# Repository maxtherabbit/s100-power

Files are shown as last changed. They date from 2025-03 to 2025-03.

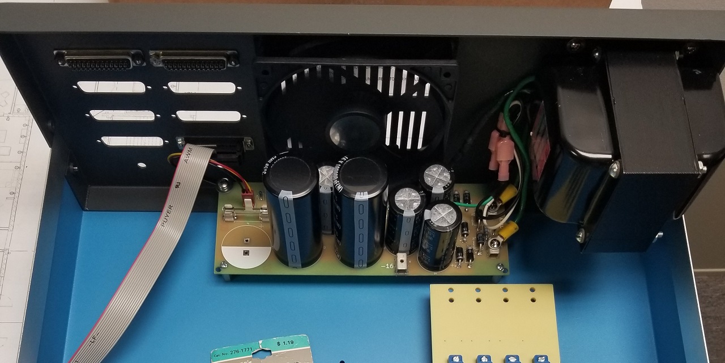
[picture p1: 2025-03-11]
20250304_174920_cover.jpg

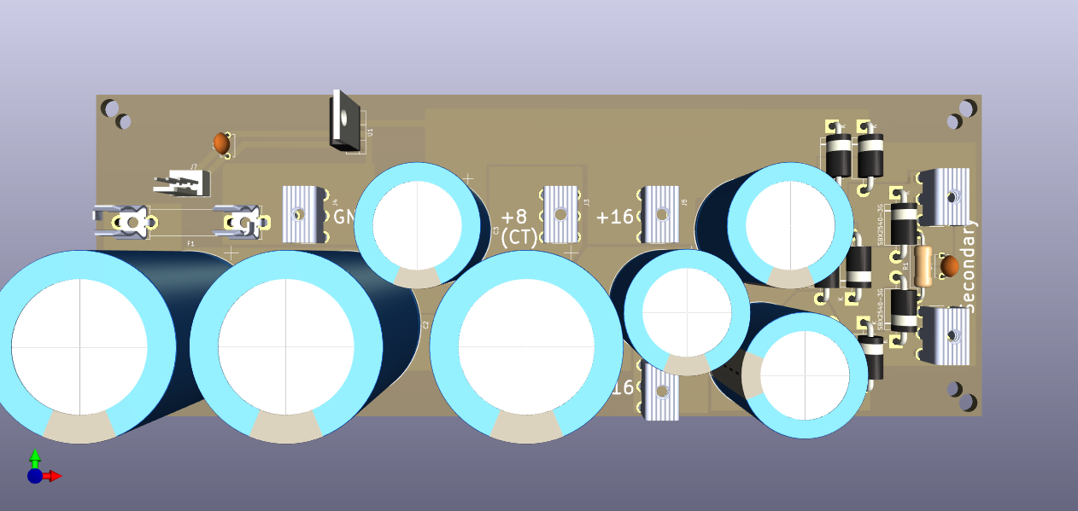
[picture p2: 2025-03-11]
s100 power.png

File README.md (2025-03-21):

# s100-power
PCB for S100 Power Supply which fits both original Altair and Clone cabinets

Based on circuit designed by Gifford Toole. Provides 10A (with Hammond 167S12) or 20A (with Hammond 167V12) total current. Mounting provisions for both original Altair cabinet as well as clone cabniet designed by Mike Douglas.
My clone cabinet was purchased from https://adwaterandstir.com/ in 2024 and uses M4 hardware. The original one sold by Mike might use 6-32 instead. Make sure you check this before ordering the standoffs!
For the one using M4, I included appropriate length standoffs in the BOM. The M4 ones attach to the screws which connect the rear panel to the bottom panel. Get longer M4 screws and thread them into the existing welded screw bosses from the bottom, then attach standoffs to them. Affix the longer 4-40 standoffs to the front of the PCB with 4-40 screws, then bolt PCB to M4 standoffs with the original M4 screws which came with the cabniet.

I found that the Hammond 167S12 transformer fit the two pre-drilled holes in the rear panel, on the right side. You will need to drill two additional holes above the pre-drilled ones at the same width apart to secure the transformer properly.

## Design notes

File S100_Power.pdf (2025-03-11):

## GEFH H(, o E

s

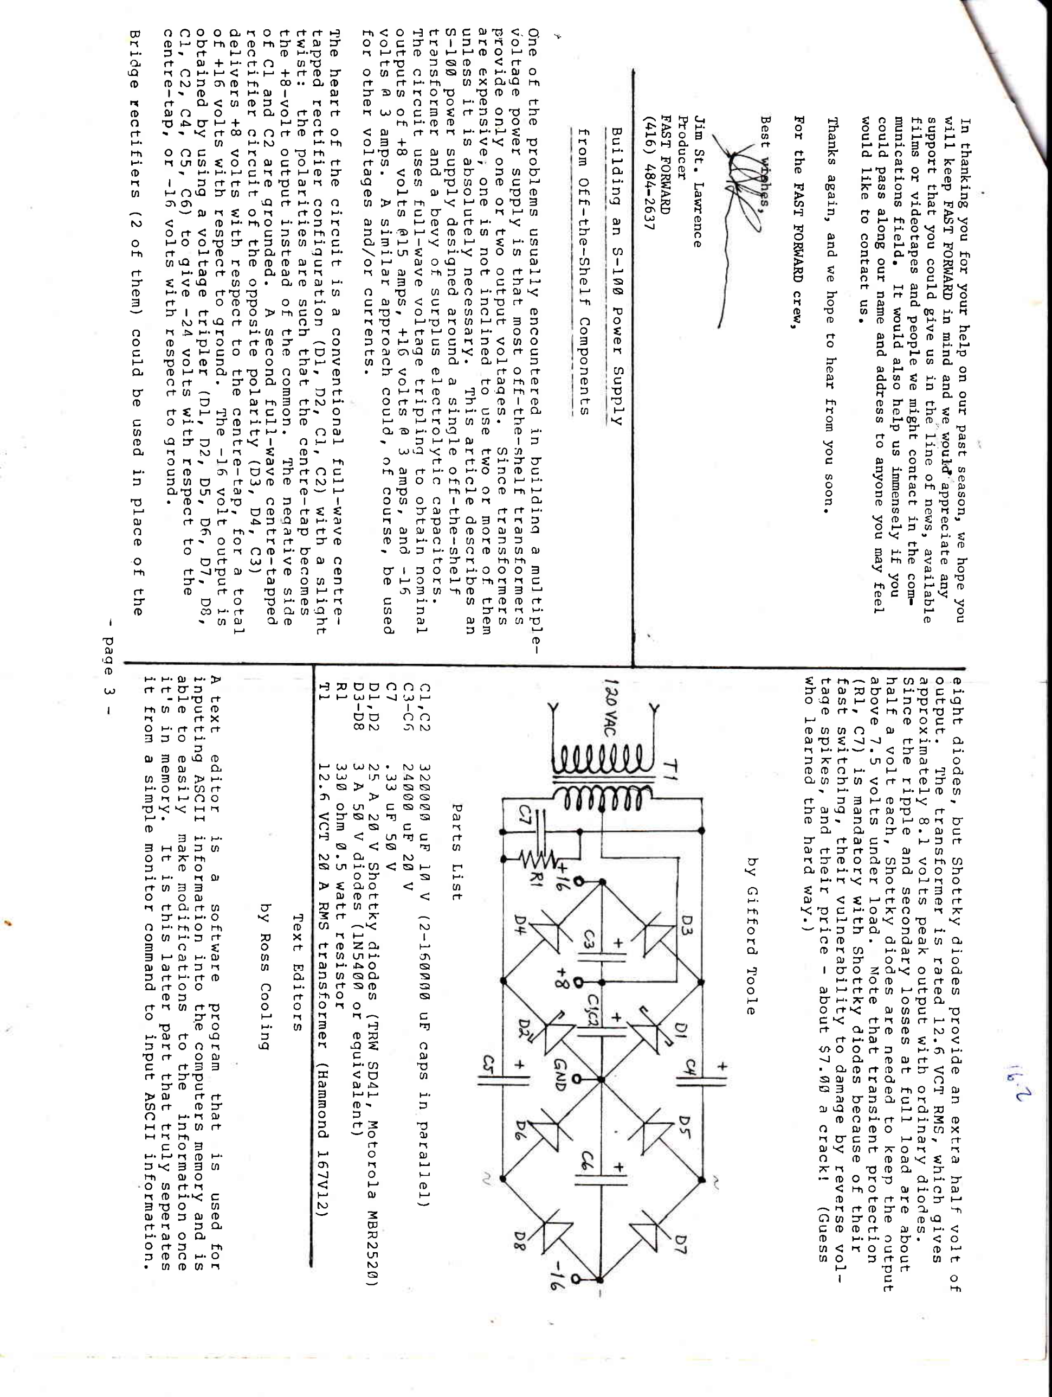
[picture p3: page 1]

rd | H | d O E Fho { H
o | y | o o c P.C P.5 FI | $ | tr d 5 HE H
5 | HHH.3'o | Hd d | 7f | oQ.o | o o | :t J | o | !) | FtFo) oHEdodoS D | H.F] H.E | O F rn | 0q | ,f o O | m'O P.
(a | F. | o H. o rt@ H | 3 | doJ | o.db ! | O HrrO | tE< rri | O H.og | Fro O | O | OSodO | -t
F | !] | octq H0, c rd
{ | o- | 5 | O'O | O Hl
F | { | !) 6 | 0 0
t | o | oE | dF=tsi
fr | H0rHiu\<
o | !t | 5d5o,tJo FlOtrAro.t
O | 'o | o41 | 0sp.rt € | o | . o OE P.5 . | tro< | !t fr | p) Ho O E O
o | 5 o.'d | H.H o. Htr 5'd 5 | oJooo. o | grH | o pr | a-o d H.$ 5 Ft | a.o o 5 5
|l | 0.o h | o ItE d | tr Fl | O O H,it{ Fl
o | o HoQ O O
!H+!
- n -i-€p
o | ho5trd C | D | OOrt' 5 ts. J | 6.a o | yEdo | :o
o | o B 0, hp p) O | 5oO | 'do 5 | (D5fr5EO . | a | oB5 \< o F.{ o. o H5 0 () C< | . r.{ f | aro E ts.:'AJ fr O hto < o:]. goro

< o p.0rrd rto O HE O
o 6 E pjY oacrY

FHO at

tE
o
a
d

o'H o. cu) tsio d
SO @iI, o.
tst s'= | tr{ r>0, NiD | €
o\t | H
(!o!5
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
'ld.5
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
af :t
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
@ o oo o o,Fr o rtrtrt€ | rr|< o €rt(/lc orc, <.o Fr O }.(rFhO O rn:fd 0, !t O O tr 5x I 5 Fr Fr O J
ts. ,..r | FO | OP.TOO | FlPr?OOPHOOf-O
O, ri | o +P.rf.) | oE | r?! | f aO | < rt lQ (.)H.P<H. | l-+rtO!t | OOtrOOEoOts'o,O
O | ON:,5\OFtr | o..OJO | rt | rtF'Hr | OXO,tO;6
l- O iH.O | I | O :tDOrrOrO | rCOO
E | .r | O,<OO5< | nl-l | O | OnOts.O | rr
o | o.) | o | no,ortorf | Fr(r)ogStrrJOld5
O E,sEP+ | P:tO | iarH'OO | (/)JOo
rt | r-<.r@Or).f | OffO | <O | r+FlriP'P'P€ P. | O P.N | P.Hr O3+ | O<<Ord Fh ootr | <x | o'uFh | HECDtr0ro | o | nFl P. nUnO{OOOtrOP.rt | rtO | (/)lCOt-.O | O
o | t H.H.PCrrriHoit | 0r. <oo,'dcr | 5o<,
n | I | f dfrP.Ot,or11O | !O O(n lOmOOtrP
a | P .)o 5t, - | tr n | o | P | o, Po 5 r5 o
JrOr | \QdH'oo | o>r+Hl | <PooE=
-Orr€OFl | rtop. | OgU | tr | nPU)
orr<of+ | trf oho | 5P..a)P<oOo.t | G
O | POOiO:trtrOOH.tr | O,=lPl<OP | {H'(, Hi rt | HO | 50,rf | -2P' | \H'Ln{ | H'<)OOC
Olo.fOFIOOOOTCTT | Ots | 0rO@ | O | O
rr | P.o.ro | oonF( | F.l0rD<HlJ5rfOr+F
:t | €<Q | oor | o,o0rP. | n3o | oo | cJP O | P'OOrrro'U | fim | O ! | oO,OP'rto<
a | n | ooE | ooP. | coro<c | o5!rr
5ld | oo>Fntro0r | '1'd- | onoooc | o
NJFt(Or+O | O5 | ntl | PrdFlOHd=:l
o | n,5ts.F! | P.aftJ | o | oFr+rfHocrP. | oo O | O rdOrrrtoJ | ^O | fOF-1rtrCHJ<OO
g | O< FtrO OO OrtU:, | rtD'o\u2 O5<OOrttr H 15OOJ | O | JP< | OO | o | Or. OJP I
O | OPFlOJrtrOSOotr | 1P .:t< | O | ffOrt O.f | .:tOO,Orf | 5 | Or?Por | rtDHlO (, | cro^ | OP
=
Urt | OPnO | FiOOHtr
O | U | 0ri11=.rNp. | Odts.OO:t | O lO rr{ PFlo nE o :t\ o | c orc.rP'P'Go.}o,
g | oP.r 5(DP.H5O | f | P | P(lmO.:t
o | rr | o 5 rl P. | c)0, | o,oP.o!2 | o | o P.
o | rC:tU | rf< | | OPP | - | 5-P0, | I f
Or 6 | Nli | { | Oi | (r(-l<O(f"(ryt
CFtr pO^Otrl5 | h | C | d | rr{H.:tU P. CO | O\lU<5.f | OC | Fnor.f P'OP'OrOC
J | JmO | -u,OO6N)P | 30.)Fno | oPP' O,lcLn<or- | O-P | OE | HIPCOrnP .d | . or O'O | O J I | I | O o o o I o n | o,
H | O | P. UOO.r{{ | c.:rxrrt | -rtts' o, | .rOrt | ,E:J-O0rP'o | n | rr!JO,EFr45 O | ,l | Fn- criJror+< | OO,OJqTOOCOT0TO
o | fi- o o | Fr cr yo | o f P.o I (]0 Fl f,:,
o | c(.)oP.(t | - oJ:rP.oooooo .O | O.r | @l<OO,O | -:YB | Fhrn
Fh | ft-Irdor-rroO | O | CtlSOOP'OOOts :t. c | 0, ooJ | oPcnts(ttiFlnc (t | O | rtrr | T,oEPrr | .,l3o'nA | 1="
J | U O ld P.O P.Fi | g | P.. | O r"O O d
O | ,:oP.rt | O O,to'O O | O 5 | 56 6 P'
- O 0J C,O J I | O O | llr O O OE P | rf | o, P | 5=
o

I
{ rt t+r^ !to, o iU o.*2 (n P

O dr ts
oooo 0,'O { -I Fl P. P'v Axrt OOOP'

o,m 5(/,

tP'
rr Ja
=r

q, uC O)
o 5. 5
c, o, :t | ri o, orrf:'rf (, | 11 5(D O

P.F1 <
c.) | {Fr P. | 0, <t tsh | <5 C P.
Hr | . Fl tsrf P'5 it F.r | OO
o, | | | (D6(,)
!'5 rl | I(IO
o | | | ts.rt
O | | | O, Hd
ts | | | (tF.7r
O | | | O ri<
rr | O,

## CT P. rro o -J C, ' o'o sc, m

| | | a3t(, ,JtC o
| | | oo oa, Fi (t c
o'< O
oo

## ,Y Ft '-oo<Hr

| | | o an r+ 6)o5 troo

### OP. o<Fl lro

| | | P
| | | I

.o
0J\

(+
@
rr

lnrt

-J | Tt P.. O.
. <:t! | e. (,O O 0J | O
P | afF:oJ <.rFro5o O H.tsO O

POiU<
rrorT, | rt
o o Pco6 ct :to. | 0J c
C. ts5.t 50r../] o(,)J<h(./) o:to,o o :,
n O Hn O
naftan Prt o o o ri
o 7io x 7tr
O. JOts.
. O,OJ0J (/) O. ts.o ir | F. OF.t FtO zo,<o0,o, oo una iro Prro o
o oEo, 0rotr | ro
rtF1oaitsF.t
5(D O | Ni O
q, | O€. | <
ct 5 | P'c\ P.
O llJ rt | O, rforrS<O t'l Or | C) !, O FfiO rJ 0,
5 Og.r | f
o | Ho,io ts.arHP.3O
oo 5(nx 5 | Ho\ | rt rl-o | r | \
o 0,K { t, 1Joc, | !t Fr :J | O. P' :, O 0, P.O 0J rf-FiO:'P
o lto 1 | 5
O O or! .t | O, t ts.< P.C (r. < o
otro | oP 5rttr | An 'O rr tro

fth

(! (!NJ. | N t! (, | lrr (! E N)
s> | qJas
o ur tr sl!
:'GNFq | S
Esc
Q <S | rn
.OJN) (n P.cD < E ts o5 | s

### r+orr

nx
Frts | I
A ZD, | P (n (n P. | ('l
P. lAO | A
o ao. | s
rt SO | S Oos
Fl 0
i^ | C
€F4 oio .a€ | o
tr0) P,A | E <o | m

q'ls
PF- | H,
O\ | I
ft= | i5
vo | c,
rt | Fl
OOJ FIE
OHPO
Q,P

=c! F
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
ota o
O0, | O, m3Cn>H.
H'O | P.(/td
=

F1 p.)O
id<< Hn
o
! P.P.
3 Ho, J o
O fr irHr 5 | rD0
P.Fr | H 0, rraZZ o o0,
6dO,d'O | U
:tts.P'O | < | €
O H.FhO Fn | | | | | | | | | O
o o ts.5 rr | D x
3c){o.t 3 PO, P.o | O
(}, 0, rr5 x | o | tT, 5 rtts.fo | O, O,rtO O | r) | ts. (D5 | o | rr .r\orrt, | o | o
o | -:rFi | P | n
rC OO | ts' A
P.O at \O | 5
,FrOOF1 | r.Q rcff | o0, tr | rtE
rr rt:t! | =
5(D g
>o | ftn tr)rr | O:t r) | ts.r1 0, HriSOar
Htst | Hl troE
P.|. | rJ O P.
5< 3 E m
Fn oo
o o rfn Ft o P.< g
ETJ O A
oo5o,(D r+Fr 5 0, P.0, o or O rr5 Fh f O O P'O

. OOOrt

0r:'Utn O.O (ro ts.! tr P. O P5! rrQ < Fno Fr! !t O oogrr 0, Xd

PPUP\.1 'lEour)oo'JP lrlr Utf | .)O @N | .'IN

ts.ts.or P.>
rfrit | 5
- Hrd rt ho o s o FJ | rtx O P.rtdct

aJOP.

I
!
0)
'o
o

I

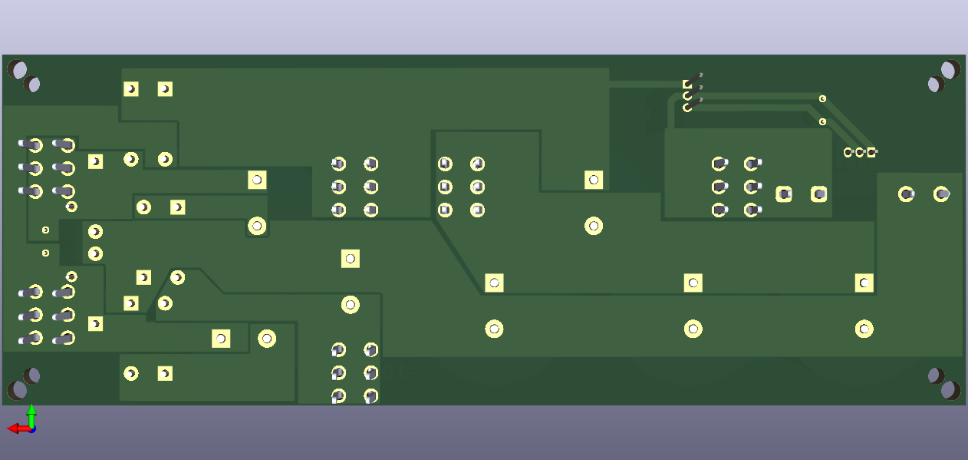
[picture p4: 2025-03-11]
s100 power back.png

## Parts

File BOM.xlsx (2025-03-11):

Reference | Quantity | Type/Value | Digikey Part | Vendor Part | Notes
C1, C2, C8 | 3 | CAP ALUM 100000UF 20% 16V SNAP | 565-ESMH160VNN104MA80U-ND | ESMH160VNN104MA80U | C8 is optional
C3-C6 | 4 | CAP ALUM 22000UF 20% 25V SNAP TH | 493-7259-ND | LLS1E223MELA
D1-D2 | 2 | DIODE SCHOTTKY 40V 25A AXIAL | 4878-SBX2540-3GCT-ND | SBX2540-3G
D3-D8 | 6 | 1N5400 or equivalent
C7 | 1 | CAP CER 0.33UF 50V X7R RADIAL | 445-173379-1-ND | FG24X7R1H334KNT06
R1 | 1 | 330 ohm 1/2 Watt Resistor
F1 | 2 | FUSE CLIP FOR 1/4" DIA. FUSE | 36-3500-ND | 3500
J1-J6 | 6 | TERM SCREW 6-32 6 PIN PCB | 36-8197-ND | 8197
J7 | 1 | CONN HEADER VERT 3POS 2.54MM | WM4112-ND | 22272031 | Optional for cooling fan
C9 | 1 | CAP CER 0.1UF 50V X7R RADIAL | 445-FK28X7R1H104KN000-ND | FK28X7R1H104KN000 | Optional for cooling fan
U1 | 1 | 7812 Linear Regulator |  |  | Optional for cooling fan
N/A | 2 | HEX SPACER M4 STEEL 12MM | 732-10555-ND | 970120471 | For mounting in Altair Clone cab attach to existing screw bosses on rear panel of cabinet and bolt to PCB with M4 screws
N/A | 2 | 1/4 HEX X 5/8 LENGTH | 1772-2618-ND | 2106-440-AL-6 | For mounting in Altair Clone cab attach these to front of PCB with 4-40 screws
T1 | 1 | 12.6V CT, 115 VAC, 60 Hz Transformer |  | Hammond 167V12 or 167S12 | Recommend 167S12 (10A) for easier mounting in Altair Clone cabinet

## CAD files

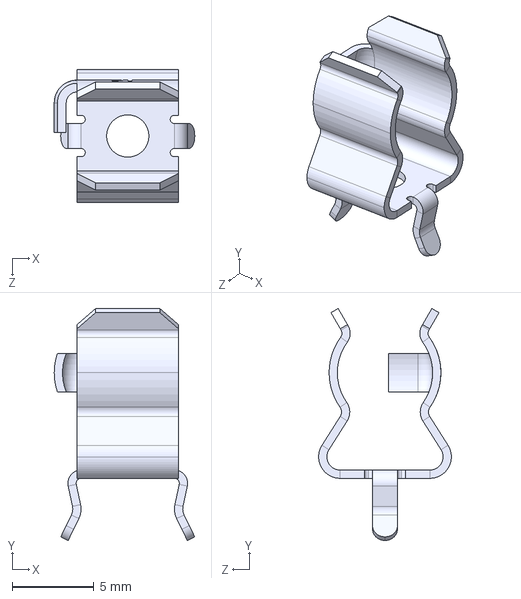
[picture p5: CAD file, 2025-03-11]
3500.STEP
8.62 x 14.2 x 8.14 mm

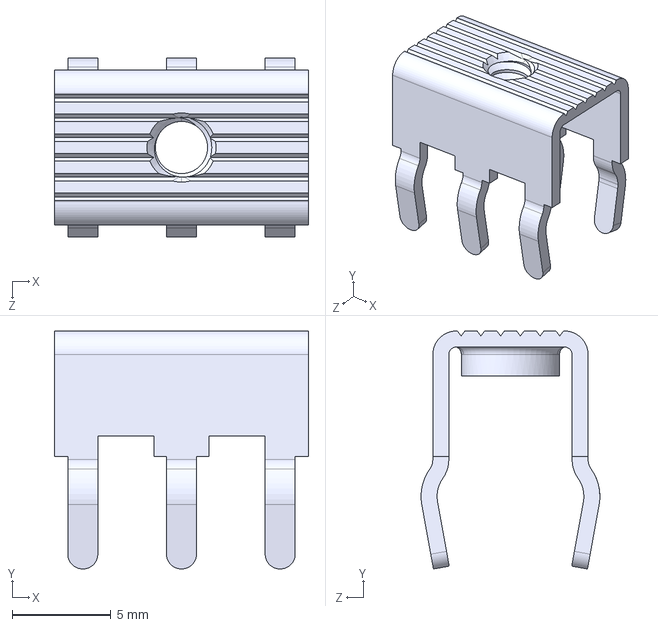
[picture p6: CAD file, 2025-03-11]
8197/8197.step
12.9 x 12.1 x 9.06 mm

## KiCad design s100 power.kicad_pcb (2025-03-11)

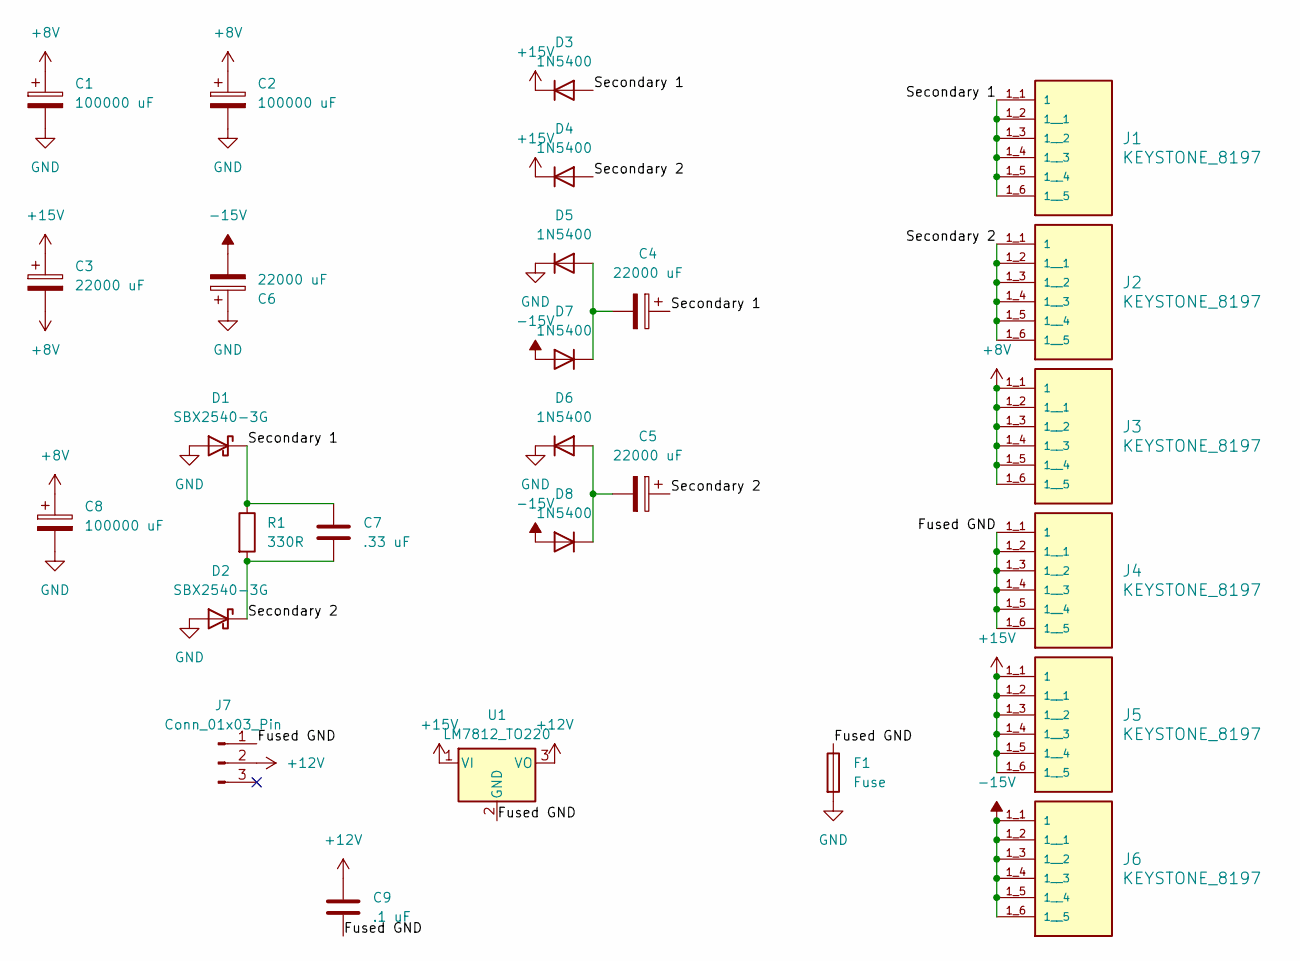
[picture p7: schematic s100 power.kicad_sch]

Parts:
C1, C2, C8: 100000 uF; CP_Radial_D35.0mm_P10.00mm_SnapIn
C3, C4, C5, C6: 22000 uF; CP_Radial_D25.0mm_P10.00mm_SnapIn
C7: .33 uF; C_Disc_D5.1mm_W3.2mm_P5.00mm
C9: .1 uF; C_Disc_D5.1mm_W3.2mm_P5.00mm
D1, D2: SBX2540-3G; D_DO-201AD_P15.24mm_Horizontal
D3, D4, D5, D6, D7, D8: 1N5400; D_DO-201AD_P15.24mm_Horizontal
F1: Fuse; Fuseholder_Clip-6.3x32mm_Littelfuse_122_Inline_P34.21x7.62m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
J1, J2, J3, J4, J5, J6: KEYSTONE_8197; PARTREV C
J7: Conn_01x03_Pin; Molex_KK-254_AE-6410-03A_1x03_P2.54mm_Vertical
R1: 330R; R_Axial_DIN0411_L9.9mm_D3.6mm_P15.24mm_Horizontal
U1: LM7812_TO220; TO-220-3_Vertical

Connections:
+8V: C1.1, C2.1, C3.2, C8.1, J3.1_1 (1), J3.1_2 (1__1), J3.1_3 (1__2), J3.1_4 (1__3), J3.1_5 (1__4), J3.1_6 (1__5)
+12V: C9.1, J7.2, U1.3 (VO)
+15V: C3.1, D3.1 (K), D4.1 (K), J5.1_1 (1), J5.1_2 (1__1), J5.1_3 (1__2), J5.1_4 (1__3), J5.1_5 (1__4), J5.1_6 (1__5), U1.1 (VI)
-15V: C6.2, D7.2 (A), D8.2 (A), J6.1_1 (1), J6.1_2 (1__1), J6.1_3 (1__2), J6.1_4 (1__3), J6.1_5 (1__4), J6.1_6 (1__5)
/Fused GND: C9.2, F1.1, J4.1_1 (1), J4.1_2 (1__1), J4.1_3 (1__2), J4.1_4 (1__3), J4.1_5 (1__4), J4.1_6 (1__5), J7.1, U1.2 (GND)
/Secondary 1: C4.1, C7.1, D1.1 (K), D3.2 (A), J1.1_1 (1), J1.1_2 (1__1), J1.1_3 (1__2), J1.1_4 (1__3), J1.1_5 (1__4), J1.1_6 (1__5), R1.1
/Secondary 2: C5.1, C7.2, D2.1 (K), D4.2 (A), J2.1_1 (1), J2.1_2 (1__1), J2.1_3 (1__2), J2.1_4 (1__3), J2.1_5 (1__4), J2.1_6 (1__5), R1.2
GND: C1.2, C2.2, C6.1, C8.2, D1.2 (A), D2.2 (A), D5.1 (K), D6.1 (K), F1.2
unnamed: C4.2, D5.2 (A), D7.1 (K)
unnamed: C5.2, D6.2 (A), D8.1 (K)

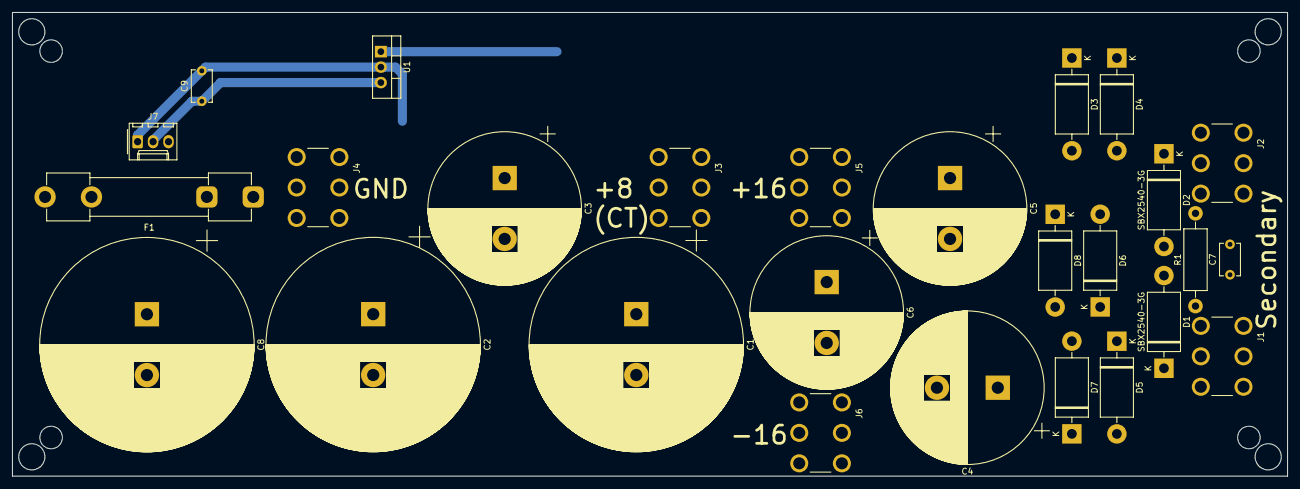
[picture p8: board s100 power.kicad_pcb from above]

Board: 2 copper layers, 209.6 x 76.2 mm, 27 parts (0 on the bottom side), 10 nets.
